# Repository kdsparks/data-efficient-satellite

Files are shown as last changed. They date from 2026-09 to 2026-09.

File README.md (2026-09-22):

# Data Efficient Satellite

## Repository Contents
### Main Program Code
- [data-tx/](https://github.com/kdsparks/data-efficient-satellite/tree/main/data-tx)
### Tester Code
- [HUSKYLENSArduino-master/](https://github.com/kdsparks/data-efficient-satellite/tree/main/HUSKYLENSArduino-master)
- [gps/](https://github.com/kdsparks/data-efficient-satellite/tree/main/gps)
- [i2c_scanner](https://github.com/kdsparks/data-efficient-satellite/tree/main/i2c_scanner)
- [imu/](https://github.com/kdsparks/data-efficient-satellite/tree/main/imu)
- [ir_array/](https://github.com/kdsparks/data-efficient-satellite/tree/main/ir_array)
- [platformio-test/](https://github.com/kdsparks/data-efficient-satellite/tree/main/platformio-test)
- [rf/](https://github.com/kdsparks/data-efficient-satellite/tree/main/rf)
- [thing-plus-rp2040/](https://github.com/kdsparks/data-efficient-satellite/tree/main/thing-plus-rp2040)
### Documents
- [HuskylensFireDetectionTraining.pdf](https://github.com/kdsparks/data-efficient-satellite/blob/main/HuskylensFireDetectionTraining.pdf)

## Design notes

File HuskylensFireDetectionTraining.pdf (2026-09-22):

## Wildfire from Space

- Store in ID1
- Press and hold learning
button on an image
- Move the husky around to get diff angles while still pressing the learning button
- Release the button
- Go to next img and click learning button again during countdown to add to ID1

Since ID2 will contain
pictures of Earth with some cloud coverage, the Husky
needs to be able to
differentiate between smoke plumes and normal clouds.
Make sure the pictures of
wildfires from space show a visible difference from normal clouds (ashy coloration, notes of flames, wind blowing
smoke in a certain direction, etc.)

https://community.dfrobot.com/mak elog-308212.html (https://community.dfrobot.com/makelog-308212.html)

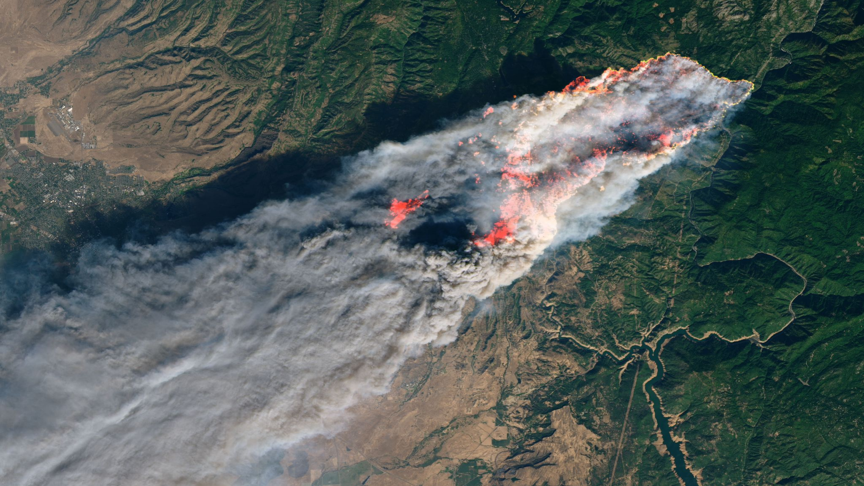
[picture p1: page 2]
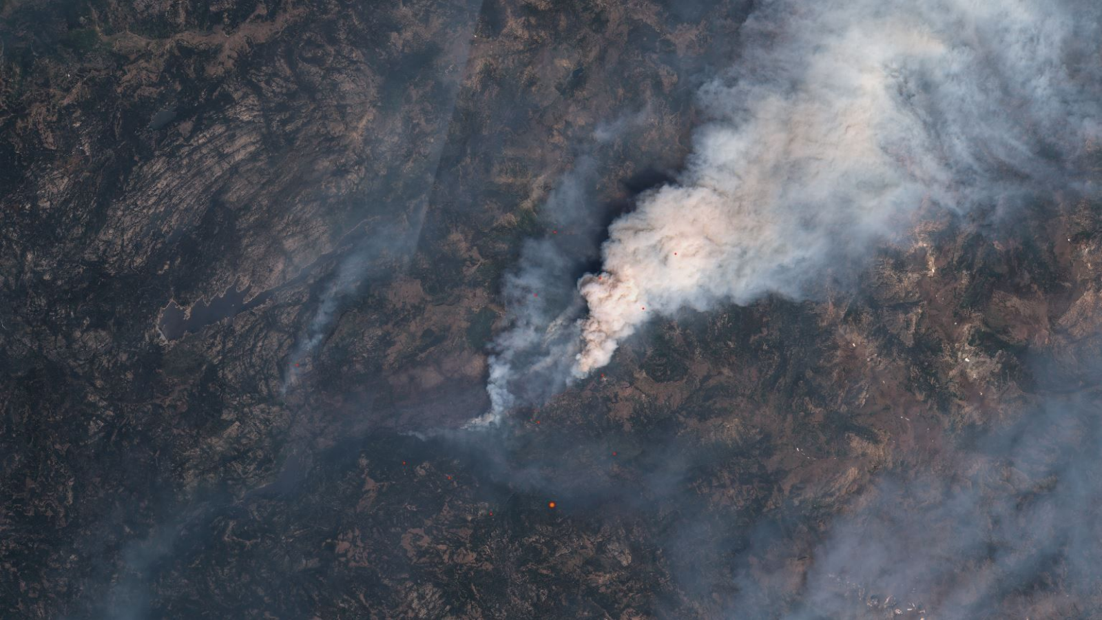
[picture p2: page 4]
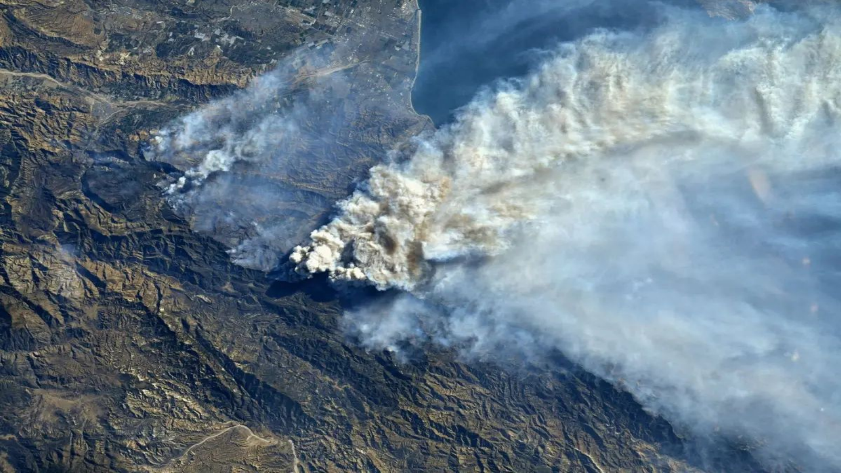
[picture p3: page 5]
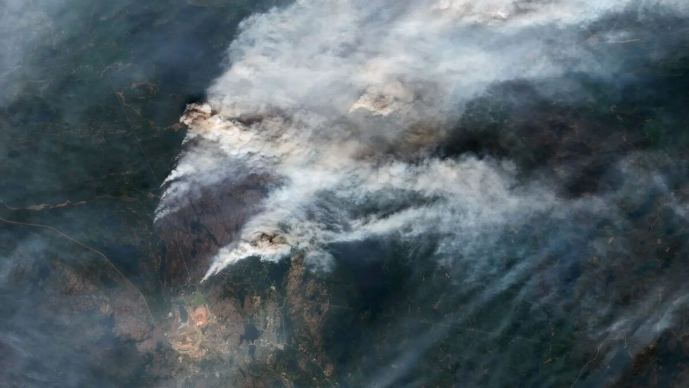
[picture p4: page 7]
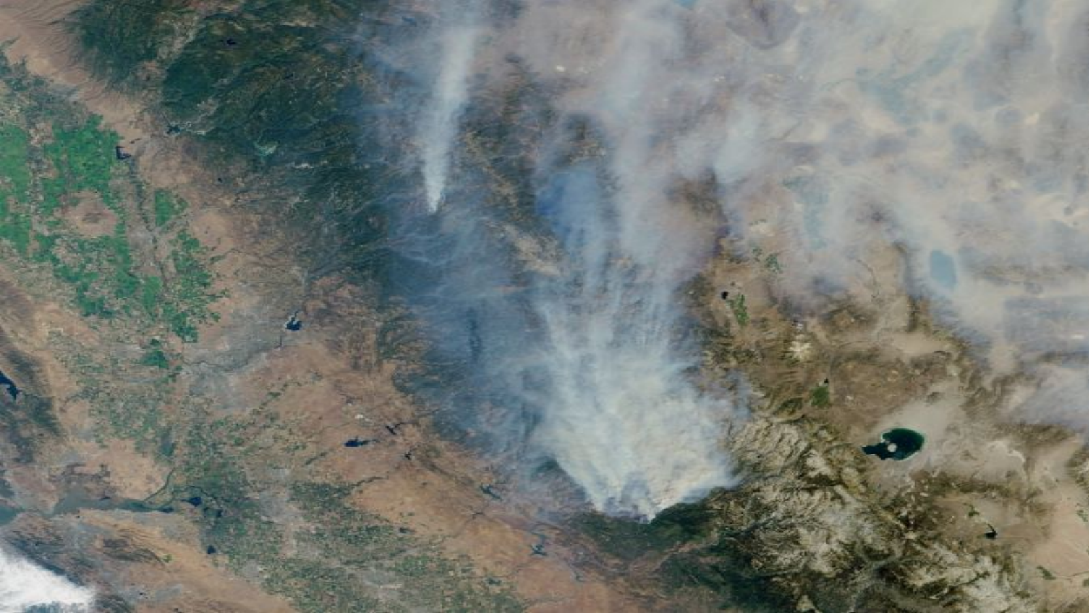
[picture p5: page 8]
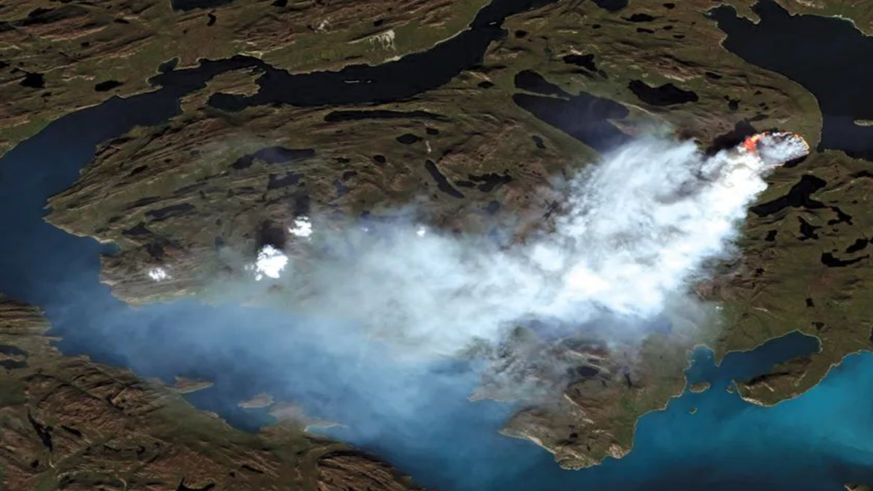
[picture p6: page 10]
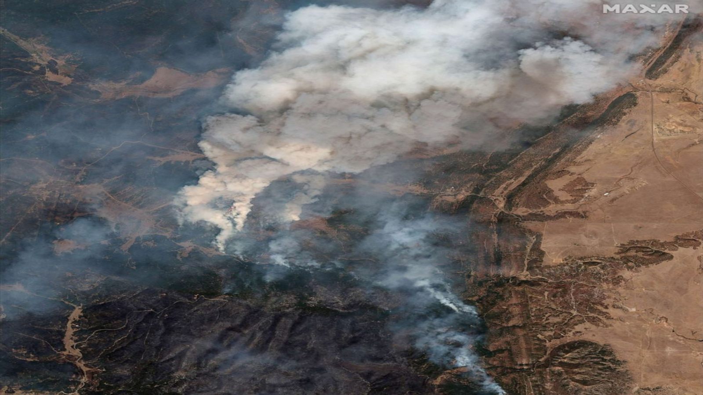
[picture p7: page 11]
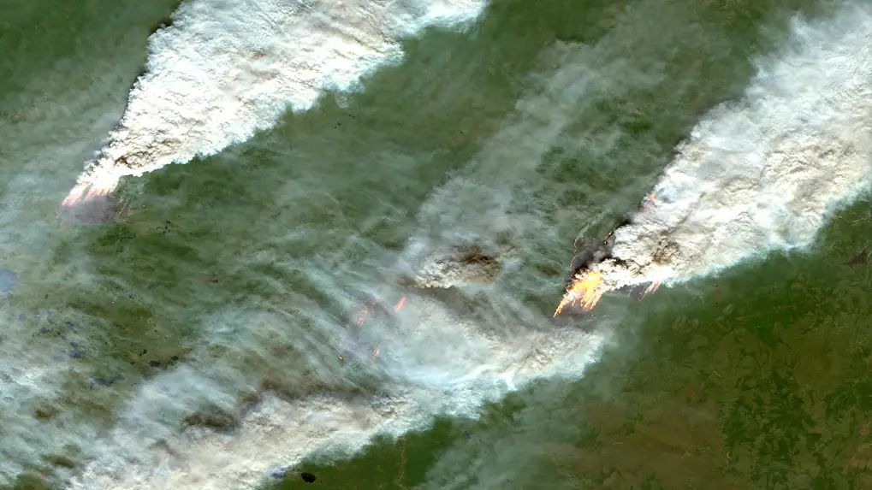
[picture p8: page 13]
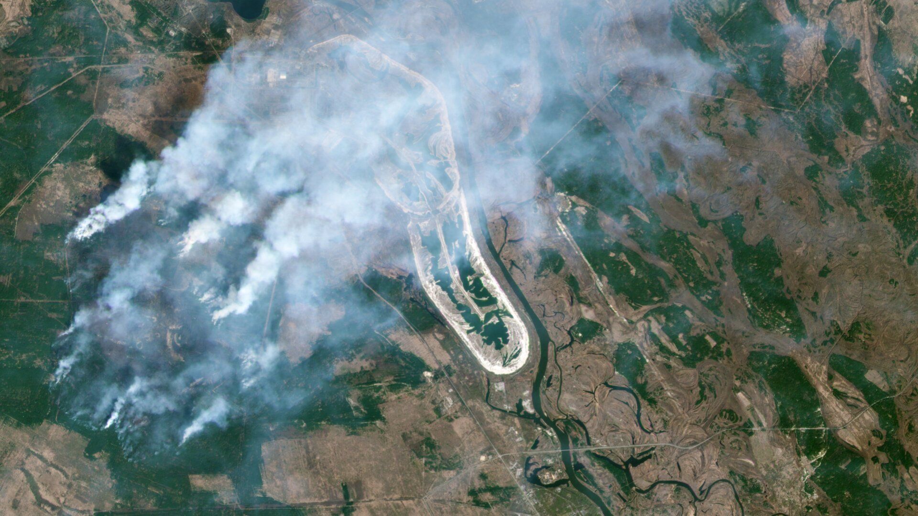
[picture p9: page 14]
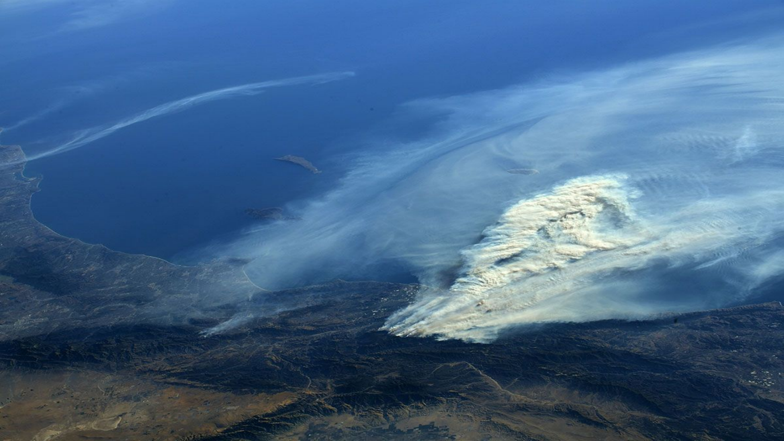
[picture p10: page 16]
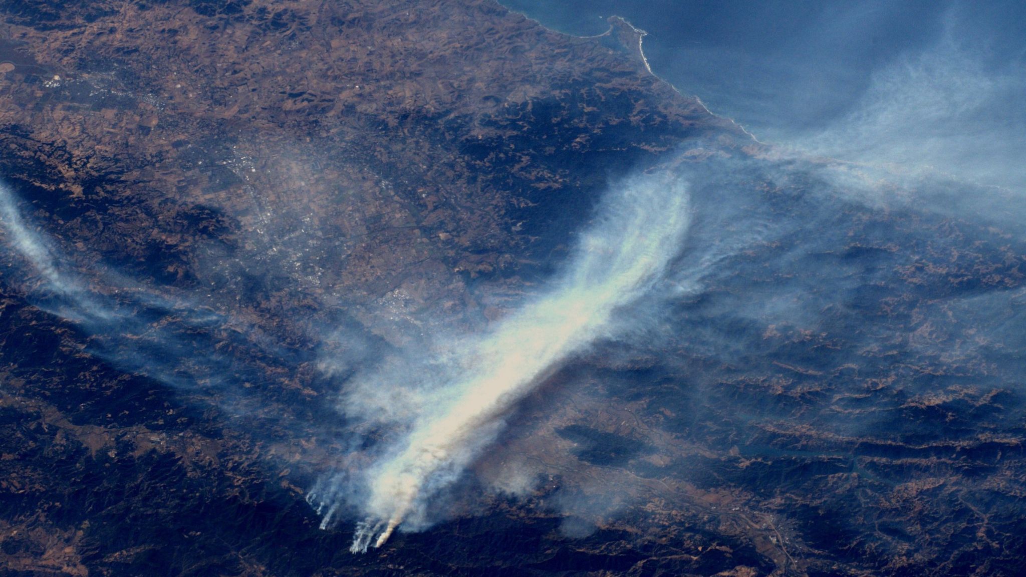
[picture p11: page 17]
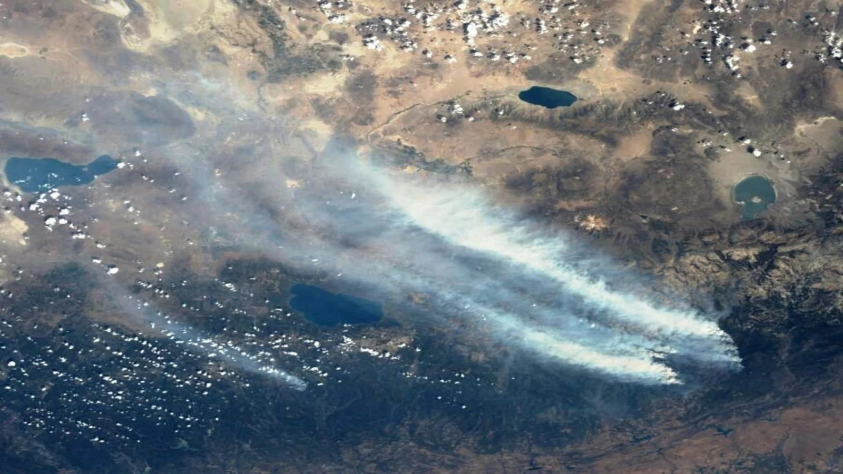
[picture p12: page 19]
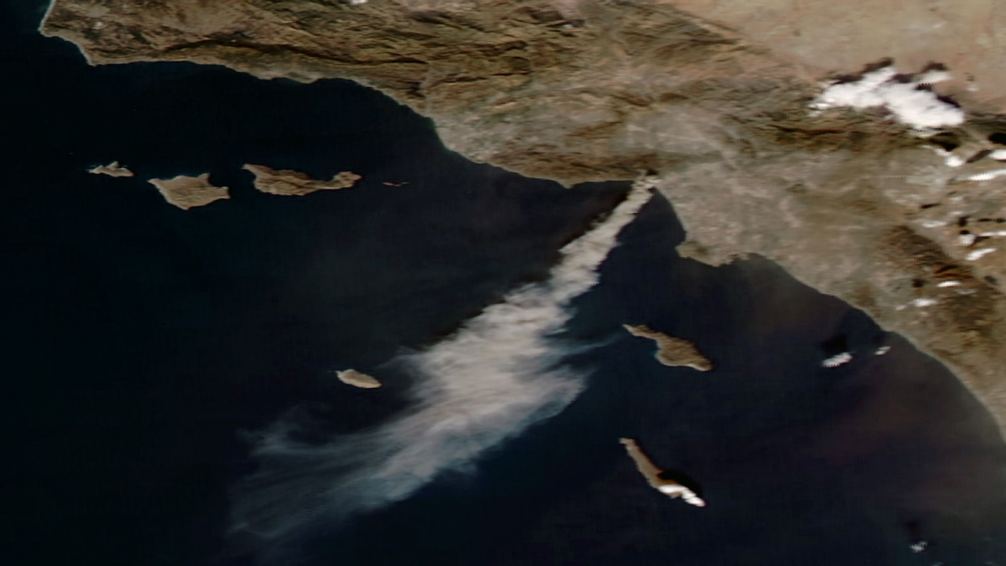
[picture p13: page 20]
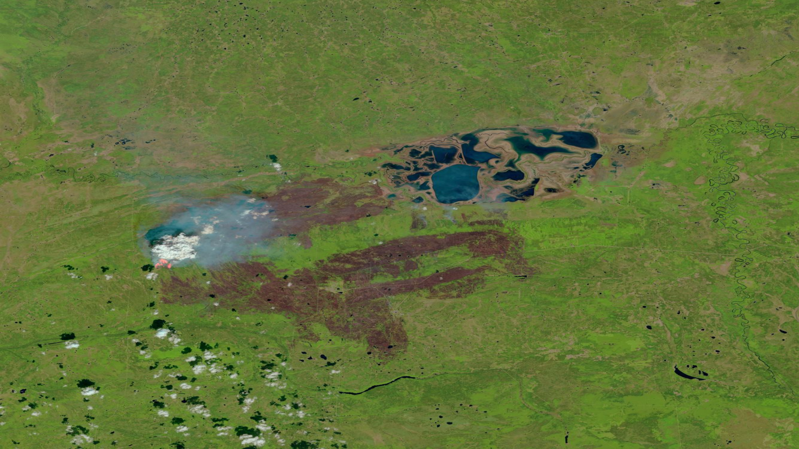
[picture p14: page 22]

## Normal Earth from Space

- Store in ID2
- Press and hold learning button on an image
- Move the husky around to get diff angles while still pressing the learning button
- Release the button
- Go to next img and click learning button again during countdown to add to ID2

If there are pictures of Earth with some cloud coverage,
make sure they are easily
distinguishable from smoke plumes in ID1.

https://community.dfrobot.com/mak elog-308212.html (https://community.dfrobot.com/makelog-308212.html)

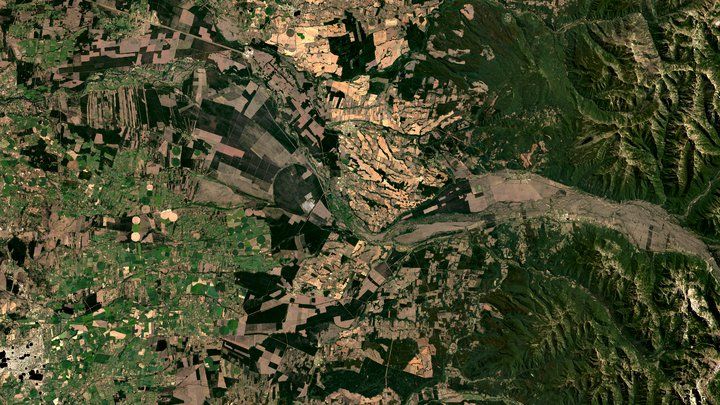
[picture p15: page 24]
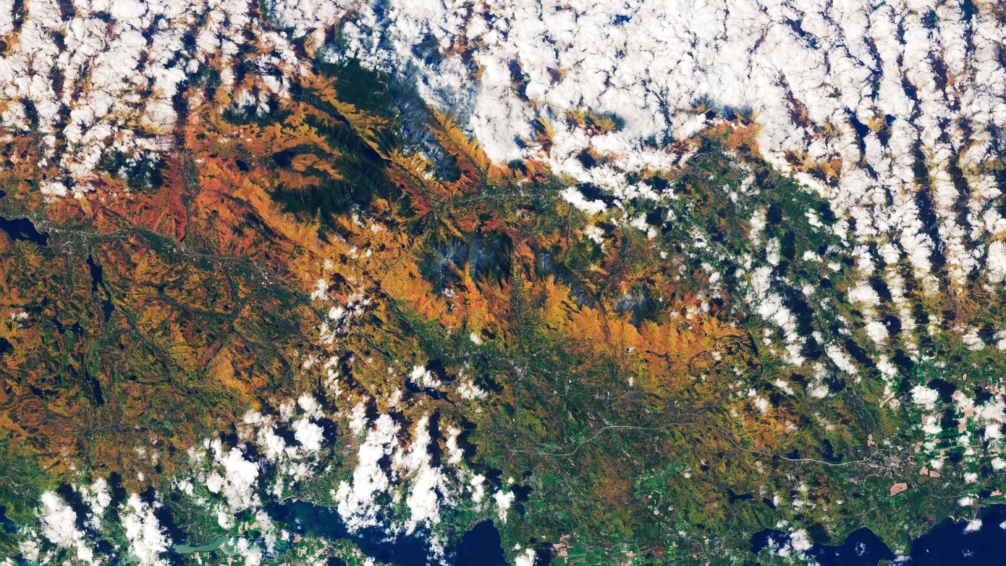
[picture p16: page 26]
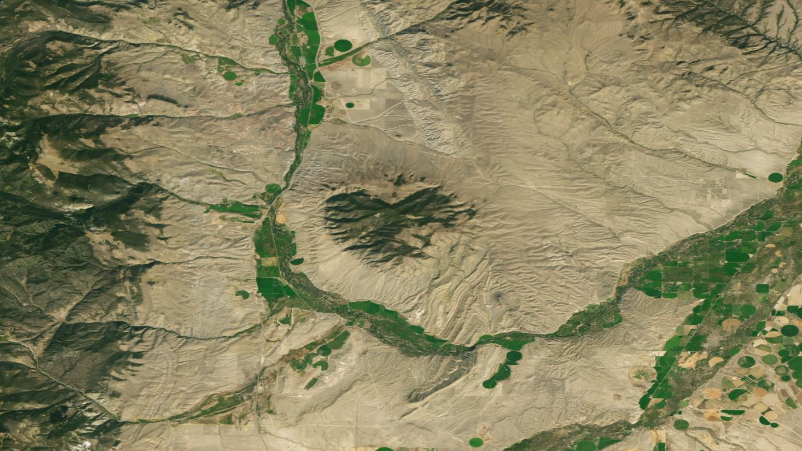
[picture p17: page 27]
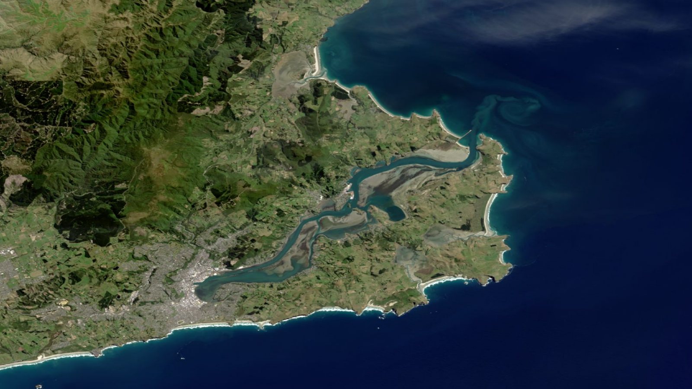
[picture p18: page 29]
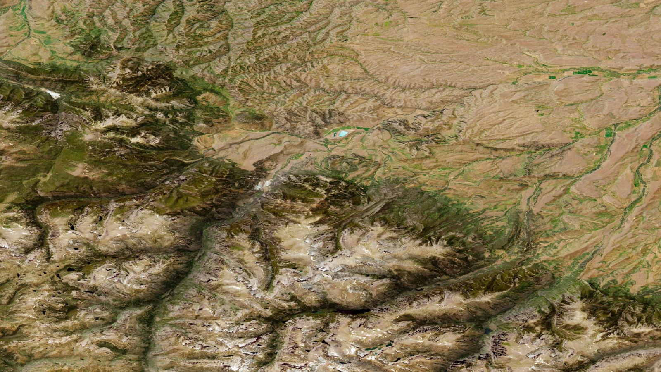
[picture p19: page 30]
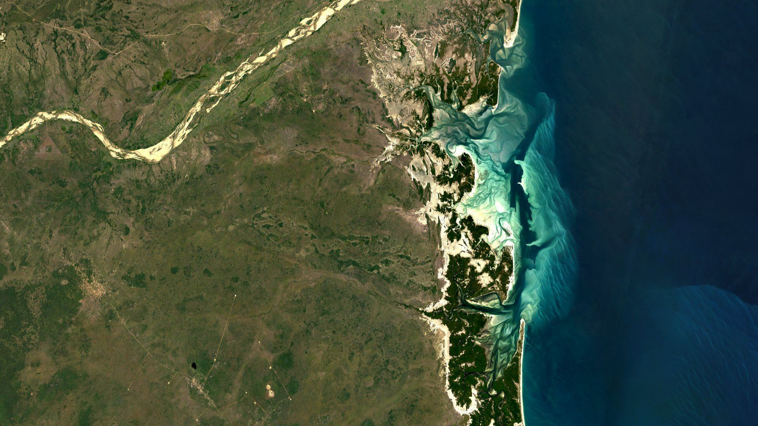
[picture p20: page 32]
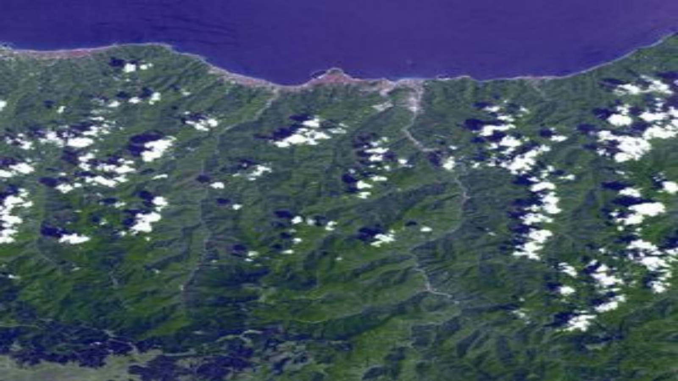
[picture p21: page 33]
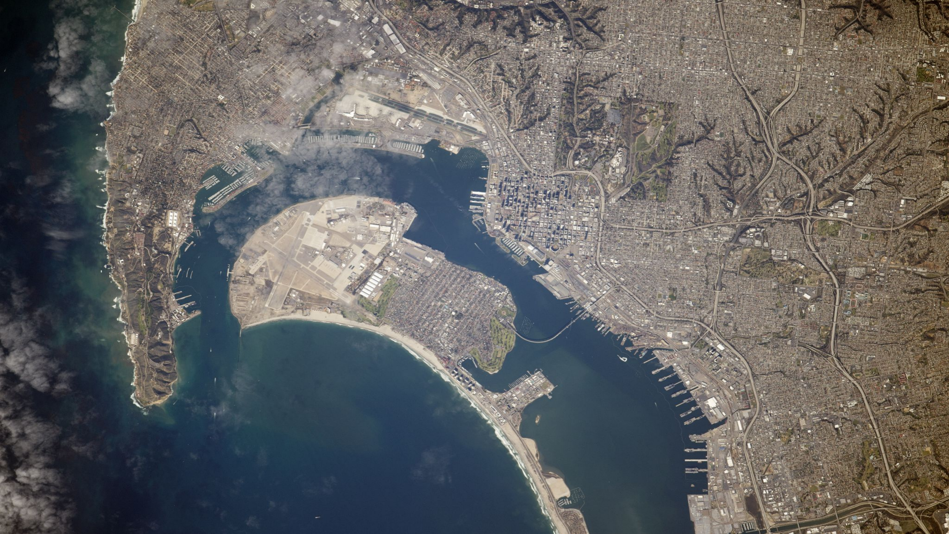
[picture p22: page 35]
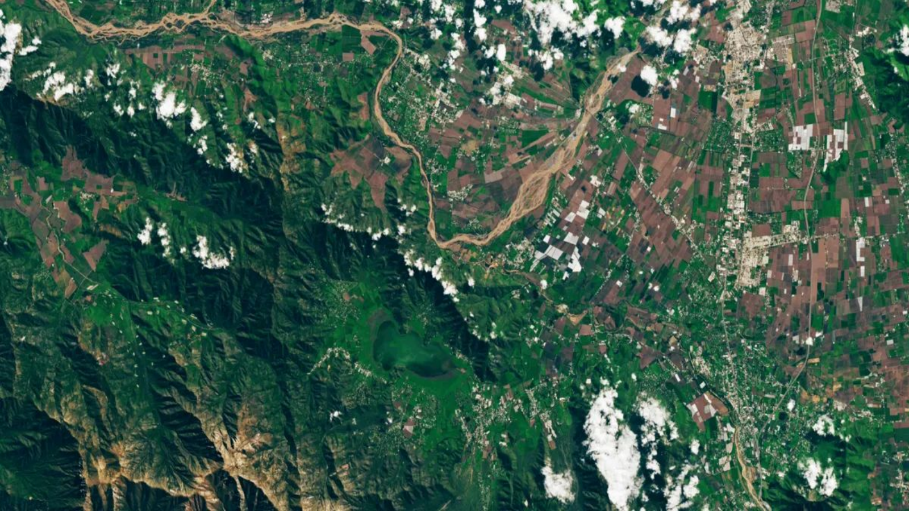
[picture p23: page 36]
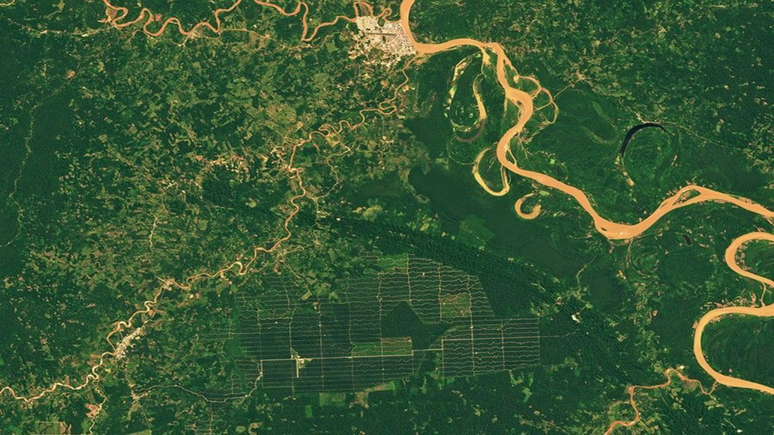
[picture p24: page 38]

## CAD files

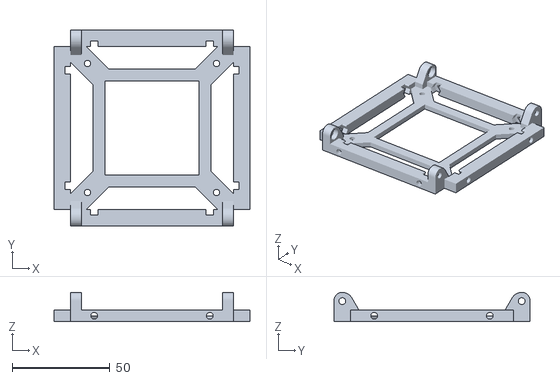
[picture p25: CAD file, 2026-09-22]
Cubesat_stl_files/Cubesat Top Frame Final.stl
100.0 x 100.0 x 15.0

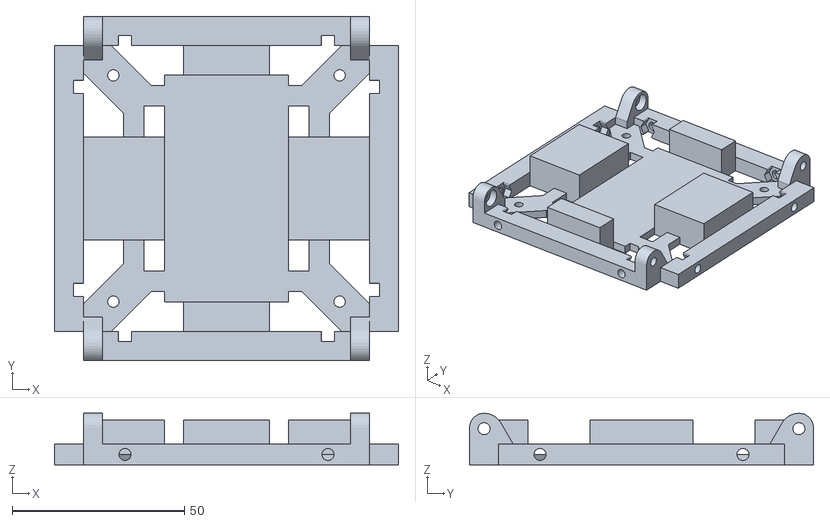
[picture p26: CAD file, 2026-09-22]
Cubesat_stl_files/Cubesat Bottom Frame Fits Battery V2.stl
100.0 x 100.0 x 15.0

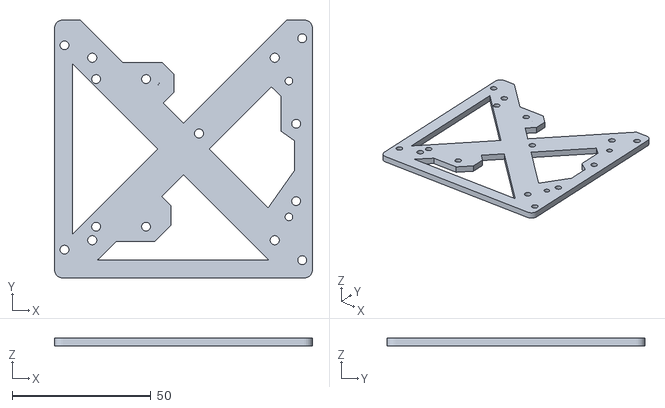
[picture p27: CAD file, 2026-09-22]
Cubesat_stl_files/Cubesat Bottom Mount V2.stl
93.0 x 93.0 x 3.00

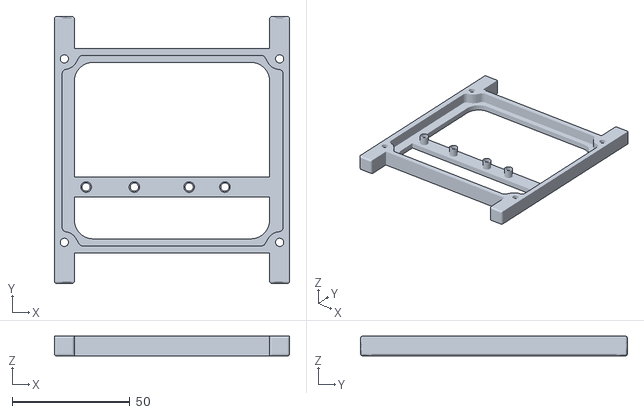
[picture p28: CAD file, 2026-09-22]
Cubesat_stl_files/Cubesat Side Frame V3.stl
100.0 x 113.5 x 8.50

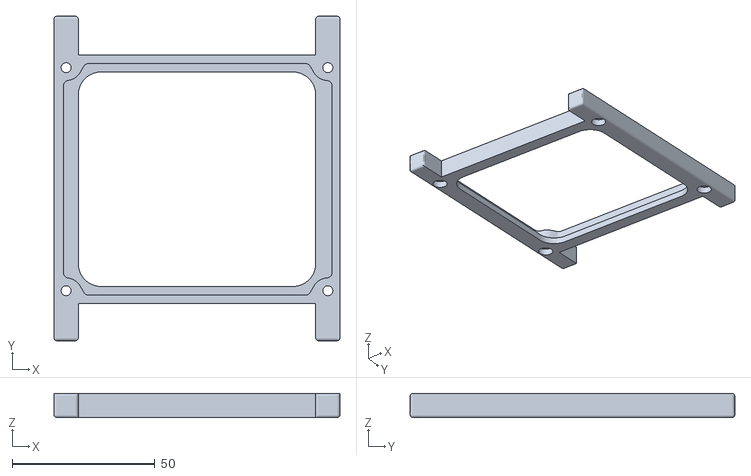
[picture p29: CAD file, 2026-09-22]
Cubesat_stl_files/Cubesat_Side_Frame_Plain.stl
100.0 x 113.5 x 8.50

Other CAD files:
Cubesat_stl_files/Cubesat GPS mount FINAL.stl

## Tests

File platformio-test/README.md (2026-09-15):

# Using this code

In order for the `HUSKYLENS` library to compile correctly, please make the following change:

```c++
// In file: /.pio/libdeps/HuskyLens/HuskyLensProtocolCore.c

// Line 135
uint8_t* husky_lens_protocol_write_begin(uint8_t command){
    send_fail = false;
    send_buffer[HEADER_0_INDEX] = 0x55;
    send_buffer[HEADER_1_INDEX] = 0xAA;
    send_buffer[ADDRESS_INDEX] = 0x11;
    send_buffer[COMMAND_INDEX] = command;
    send_index = CONTENT_INDEX;
    return send_buffer; // <--- Remove &
}
```

`send_buffer` is a `uint8_t[]` and thus is already `uint8_t*`

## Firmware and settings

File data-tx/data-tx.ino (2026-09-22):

/*
  Code adapted from:
  ***************************************************
 HUSKYLENS An Easy-to-use AI Machine Vision Sensor
  <https://www.dfrobot.com/product-1922.html>
 
  This example shows the basic function of library for HUSKYLENS via I2c.
 
  Created 2020-03-13
  By [Angelo qiao](Angelo.qiao@dfrobot.com)
 
  GNU Lesser General Public License.
  See <http://www.gnu.org/licenses/> for details.
  All above must be included in any redistribution
 ****************************************************
 Reading lat and long via UBX binary commands - no more NMEA parsing!
  By: Nathan Seidle
  SparkFun Electronics
  Date: January 3rd, 2019
  License: MIT. See license file for more information but you can
  basically do whatever you want with this code.

  This example shows how to query a u-blox module for its lat/long/altitude. We also
  turn off the NMEA output on the I2C port. This decreases the amount of I2C traffic 
  dramatically.
 ****************************************************
 SparkFun BMI270 Arduino Library: Example01_BasicReadingsI2C
 ****************************************************
 Read the temperature pixels from the MLX90640 IR array
  By: Nathan Seidle
  SparkFun Electronics
  Date: May 22nd, 2018
  License: MIT. See license file for more information but you can
  basically do whatever you want with this code.

  This example initializes the MLX90640 and outputs the 768 temperature values
  from the 768 pixels.
  ****************************************************
 Name          : CWLed.ino
  @author       : Roberto D'Amico (@Bobboteck)
  Last modified : 22.09.2021
  Revision      : 1.0.0
 
  Modification History:
  Date         Version     Modified By     Description
  2021-09-22   1.0.0       Roberto D'Amico Code Example for CWLibrary that use Arduino Built-in led to send message
  
  The MIT License (MIT)
 
  This file is part of the CWLibrary Project (https://github.com/bobboteck/CWLibrary).
 	Copyright (c) 2021 Roberto D'Amico (Bobboteck - https://bobboteck.github.io/).
 
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
  The above copyright notice and this permission notice shall be included in all
  copies or substantial portions of the Software.
*/

#include <Wire.h>
#include "HUSKYLENS.h"
#include "SparkFun_BMI270_Arduino_Library.h"
#include <SparkFun_u-blox_GNSS_Arduino_Library.h>  // http://librarymanager/All#SparkFun_u-blox_GNSS
#include "MLX90640_API.h"
#include "MLX90640_I2C_Driver.h"
#include "CWLibrary.hpp"

#define TA_SHIFT 8  // Default shift for MLX90640 in open air

HUSKYLENS huskylens;
SFE_UBLOX_GNSS myGNSS;
BMI270 imu;
paramsMLX90640 mlx90640;

uint8_t i2cAddressImu = BMI2_I2C_PRIM_ADDR;  // 0x68
const byte MLX90640_address = 0x33;          // Default 7-bit unshifted address of the MLX90640
const int DATA_SIZE_IR = 32 * 24;            // Variable for number of pixels
static float mlx90640To[768];
const int MIN_HOT_PIXELS = 25;
const int MIN_DEG_C = 30;
bool isSmokeDetected = false;
const int SMOKE_ID = 1;
const int TX_PIN = 16;
const int WPM = 15;

bool detectSmoke(HUSKYLENSResult result);
void sendPositionGNSS();
void sendAccelData();
void sendGyroData();
bool isConnectedMLX();
int detectHeat();
void txActiveAction();
void txNoActiveAction();

CWLibrary cw = CWLibrary(WPM, txActiveAction, txNoActiveAction);

void setup() {
  Serial.begin(115200);
  Wire1.begin();

  pinMode(TX_PIN, OUTPUT);

  // Set up HuskyLens
  Serial.println("Setting up HuskyLens...");
  while (!huskylens.begin(Wire1)) {
    Serial.println(F("Begin failed!"));
    Serial.println(F("1.Please recheck the \"Protocol Type\" in HUSKYLENS (General Settings>>Protocol Type>>I2C)"));
    Serial.println(F("2.Please recheck the connection."));
    delay(3000);
  }
  Serial.println("HuskyLens connected!");

  // Set up GNSS
  Serial.println("Setting up GNSS...");
  //myGNSS.enableDebugging(); // Uncomment this line to enable helpful debug messages on Serial
  while (!myGNSS.begin(Wire1)) {
    Serial.println(F("u-blox GNSS not detected at default I2C address. Please check wiring."));
    delay(3000);
  }
  myGNSS.setI2COutput(COM_TYPE_UBX);                  // Set the I2C port to output UBX only (turn off NMEA noise)
  myGNSS.saveConfigSelective(VAL_CFG_SUBSEC_IOPORT);  //Save (only) the communications port settings to flash and BBR
  Serial.println("GNSS connected!");

  // Set up IMU
  Serial.println("Setting up IMU...");
  // Check if sensor is connected and initialize
  // Address is optional (defaults to 0x68)
  while (imu.beginI2C(i2cAddressImu, Wire1) != BMI2_OK)  // added second parameter to prevent defaulting to Wire
  {
    // Not connected, inform user
    Serial.println("Error: BMI270 not connected, check wiring and I2C address!");
    delay(3000);
  }
  Serial.println("IMU connected!");

  // Set up IR Array
  Serial.println("Setting up IR Array...");
  while (!isConnectedMLX()) {
    Serial.println("MLX90640 not detected at default I2C address. Please check wiring.");
    delay(3000);
  }
  Serial.println("MLX90640 connected!");

  // Get device parameters for IR Array - We only have to do this once
  int status;
  uint16_t eeMLX90640[832];
  status = MLX90640_DumpEE(MLX90640_address, eeMLX90640);
  if (status != 0)
    Serial.println("Failed to load system parameters");

  status = MLX90640_ExtractParameters(eeMLX90640, &mlx90640);
  if (status != 0)
    Serial.println("Parameter extraction failed");
}

void loop() {
  // Get measurements from the IMU sensor. This must be called before accessing
  // the sensor data, otherwise it will never update
  imu.getSensorData();

  // Get result from HuskyLens
  if (!huskylens.request()) Serial.println(F("Fail to request data from HUSKYLENS, recheck the connection!"));
  else if (!huskylens.isLearned()) Serial.println(F("Nothing learned, press learn button on HUSKYLENS to learn one!"));
  else if (!huskylens.available()) Serial.println(F("No block or arrow appears on the screen!"));
  else {
    HUSKYLENSResult result = huskylens.read();
    isSmokeDetected = detectSmoke(result);
  }

  // Get result from IR Array
  int numHotPixels = detectHeat();

  // Potential wildfire detected
  if (isSmokeDetected && numHotPixels > MIN_HOT_PIXELS) {
    char alertPreamble[] = "??? WILDFIRE SAT/ POTENTIAL FIRE/ ";
    Serial.println(alertPreamble);
    cw.sendMessage(alertPreamble);

    sendPositionGNSS();
    sendAccelData();
    sendGyroData();

    Serial.println();
  }

  delay(1000);
}

bool detectSmoke(HUSKYLENSResult result) {
  if (result.command == COMMAND_RETURN_BLOCK) {
    if (result.ID == SMOKE_ID) {
      return true;
    }
  }
  return false;
}

// Query module only every second. Doing it more often will just cause I2C traffic
// Check the delay where this function is called to do so
void sendPositionGNSS() {
  // Send latitude
  long latitude = myGNSS.getLatitude();                   // latitude gives raw GPS reading (degrees * 10^-7)
  double actualLatitude = (double)latitude / 10000000.0;  // divide by 10,000,000 to get lat readable by google maps

  char actualLat[10];
  sprintf(actualLat, "%f", actualLatitude);
  char lat[] = "LAT ";
  Serial.print(lat);
  Serial.print(actualLat);
  cw.sendMessage(lat);
  cw.sendMessage(actualLat);

  // Send longitude
  long longitude = myGNSS.getLongitude();                   // longitude gives raw GPS reading (degrees * 10^-7)
  double actualLongitude = (double)longitude / 10000000.0;  // divide by 10,000,000 to get long readable by google maps

  char actualLong[10];
  sprintf(actualLong, "%f", actualLongitude);
  char longi[] = " LON ";
  Serial.print(longi);
  Serial.println(actualLong);
  cw.sendMessage(longi);
  cw.sendMessage(actualLong);
}

void sendAccelData() {
  char accel[] = "/ ACCEL(G) ";
  char x[] = "X: ";
  char y[] = " Y: ";
  char z[] = " Z: ";
  char accelX[10], accelY[10], accelZ[10];
  sprintf(accelX, "%f", imu.data.accelX);
  sprintf(accelY, "%f", imu.data.accelY);
  sprintf(accelZ, "%f", imu.data.accelZ);

  Serial.print(accel);
  Serial.print(x);
  Serial.print(accelX);
  Serial.print(y);
  Serial.print(accelY);
  Serial.print(z);
  Serial.println(accelZ);

  cw.sendMessage(accel);
  cw.sendMessage(x);
  cw.sendMessage(accelX);
  cw.sendMessage(y);
  cw.sendMessage(accelY);
  cw.sendMessage(z);
  cw.sendMessage(accelZ);
}

void sendGyroData() {
  char rotat[] = "/ ROTAT(DEG/S) ";
  char x[] = "X: ";
  char y[] = " Y: ";
  char z[] = " Z: ";
  char rotatX[10], rotatY[10], rotatZ[10];
  sprintf(rotatX, "%f", imu.data.gyroX);
  sprintf(rotatY, "%f", imu.data.gyroY);
  sprintf(rotatZ, "%f", imu.data.gyroZ);

  Serial.print(rotat);
  Serial.print(x);
  Serial.print(rotatX);
  Serial.print(y);
  Serial.print(rotatY);
  Serial.print(z);
  Serial.println(rotatY);

  cw.sendMessage(rotat);
  cw.sendMessage(x);
  cw.sendMessage(rotatX);
  cw.sendMessage(y);
  cw.sendMessage(rotatY);
  cw.sendMessage(z);
  cw.sendMessage(rotatZ);
}

// Returns true if the MLX90640 is detected on the I2C bus
bool isConnectedMLX() {
  Wire1.beginTransmission((uint8_t)MLX90640_address);
  if (Wire1.endTransmission() != 0)
    return (false);  // Sensor did not ACK
  return (true);
}

int detectHeat() {
  // Get Temps from IR Array
  for (byte x = 0; x < 2; x++)  // Read both subpages
  {
    uint16_t mlx90640Frame[834];
    int status = MLX90640_GetFrameData(MLX90640_address, mlx90640Frame);
    if (status < 0) {
      Serial.print("GetFrame Error: ");
      Serial.println(status);
    }

    float vdd = MLX90640_GetVdd(mlx90640Frame, &mlx90640);
    float Ta = MLX90640_GetTa(mlx90640Frame, &mlx90640);

    float tr = Ta - TA_SHIFT;  // Reflected temperature based on the sensor ambient temperature
    float emissivity = 0.95;

    MLX90640_CalculateTo(mlx90640Frame, &mlx90640, emissivity, tr, mlx90640To);
  }

  int num_hot_pixels = 0;

  for (int x = 0; x < DATA_SIZE_IR; x++) {
    float pixel_temp = mlx90640To[x];  // Reads temps of all 768 pixels
    if (pixel_temp > MIN_DEG_C)        // If the temp of a pixel is greater than the threshold...
      num_hot_pixels++;                // ...add it to the count of hot pixels
  }

  return num_hot_pixels;
}

void txActiveAction() {
  analogWrite(TX_PIN, 225);
}

void txNoActiveAction() {
  analogWrite(TX_PIN, 0);
}

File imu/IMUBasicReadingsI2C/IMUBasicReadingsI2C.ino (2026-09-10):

// Adapted from the SparkFun BMI270 Arduino Library: Example01_BasicReadingsI2C

#include <Wire.h>
#include "SparkFun_BMI270_Arduino_Library.h"

// Create a new sensor object
BMI270 imu;

// I2C address selection
uint8_t i2cAddress = BMI2_I2C_PRIM_ADDR; // 0x68
// uint8_t i2cAddress = BMI2_I2C_SEC_ADDR; // 0x69

void setup()
{
    // Start serial
    Serial.begin(115200);
    Serial.println("BMI270 Example 1 - Basic Readings I2C");

    // Initialize the I2C library
    Wire1.begin(); // changed from Wire to Wire1 for Thing Plus RP2040

    // Check if sensor is connected and initialize
    // Address is optional (defaults to 0x68)
    while (imu.beginI2C(i2cAddress, Wire1) != BMI2_OK) // added second parameter to prevent defaulting to Wire
    {
        // Not connected, inform user
        Serial.println("Error: BMI270 not connected, check wiring and I2C address!");

        // Wait a bit to see if connection is established
        delay(1000);
    }

    Serial.println("BMI270 connected!");
}

void loop()
{
    // Get measurements from the sensor. This must be called before accessing
    // the sensor data, otherwise it will never update
    imu.getSensorData();

    // Print acceleration data
    Serial.print("Acceleration in g's");
    Serial.print("\t");
    Serial.print("X: ");
    Serial.print(imu.data.accelX, 3);
    Serial.print("\t");
    Serial.print("Y: ");
    Serial.print(imu.data.accelY, 3);
    Serial.print("\t");
    Serial.print("Z: ");
    Serial.print(imu.data.accelZ, 3);

    Serial.print("\t");

    // Print rotation data
    Serial.print("Rotation in deg/sec");
    Serial.print("\t");
    Serial.print("X: ");
    Serial.print(imu.data.gyroX, 3);
    Serial.print("\t");
    Serial.print("Y: ");
    Serial.print(imu.data.gyroY, 3);
    Serial.print("\t");
    Serial.print("Z: ");
    Serial.println(imu.data.gyroZ, 3);

    // Print 50x per second
    delay(20);
}

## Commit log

2026-09-10 Add I2C scanner file
2026-09-10 Add imu basic readings file
2026-09-10 Add RadioHead library
    [project.cfg]
2026-09-12 wrote basic fire detection code for IR array sensor
2026-09-13 Fix writeFirmwareVersion and husky_lens_protocol_write_begin returns
    [HUSKYLENS.h]
2026-09-13 Change Wire to Wire1 in HuskyLens I2C tester file
2026-09-14 Add setup for IMU in data-tx
2026-09-14 Change Wire to Wire1 for GNSS
2026-09-15 Change Wire to Wire1 for GNSS tester file
2026-09-15 Move MLX files to data-tx directory to resolve library import issue
    [MLX90640_I2C_Driver.cpp]
2026-09-15 added platformio project instead of arduino
2026-09-15 added output to processing code for IR sensor
2026-09-20 Send imu data when smoke/fire detected
2026-09-20 Set tx pin for RP2040 in RF tester file
2026-09-22 Fix alert data format
    [data-tx.ino]
2026-09-22 Create Cubsat_stl_files
    This folder carries all the stl files used when designing the frame of the Cubesat.
2026-09-22 Rename Cubesat_stl_files to Stl Files
2026-09-22 Rename Cubesat Bottom Frame Fits Battery V2.stl to Cubesat_stl_files/Cubesat Bottom Frame Fits Battery V2.stl
    [Cubesat Bottom Frame Fits Battery V2.stl]
2026-09-22 Rename Cubesat Bottom Mount V2.stl to Cubesat_stl_files/Cubesat Bottom Mount V2.stl
    [Cubesat Bottom Mount V2.stl]
2026-09-22 Rename Cubesat GPS mount FINAL.stl to Cubesat_stl_files/Cubesat GPS mount FINAL.stl
    [Cubesat GPS mount FINAL.stl]
2026-09-22 Rename Cubesat Side Frame V3.stl to Cubesat_stl_files/Cubesat Side Frame V3.stl
    [Cubesat Side Frame V3.stl]
2026-09-22 Rename Cubesat Top Frame Final.stl to Cubesat_stl_files/Cubesat Top Frame Final.stl
    [Cubesat Top Frame Final.stl]
2026-09-22 Condense alert package and adjust min temperature and wpm for demo
